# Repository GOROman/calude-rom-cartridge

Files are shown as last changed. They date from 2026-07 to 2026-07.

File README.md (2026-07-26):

# Famicom ROM Cartridge (M5Stamp S3 + NROM/CNROM)

ファミコン実機で動作するカートリッジ基板。物理ROMの代わりに
**M5Stamp S3 (ESP32-S3)** を搭載し、電源投入時にROMイメージをSRAMへ
転送してファミコンにバスを明け渡す「SRAMロード&ハンドオーバー方式」を
採用しています。NROM/CNROMに対応し、ES8388によるI2S音声ミックスと
SLG46826G GreenPAKによるOPMレジスタ捕捉回路をオプション搭載できます。

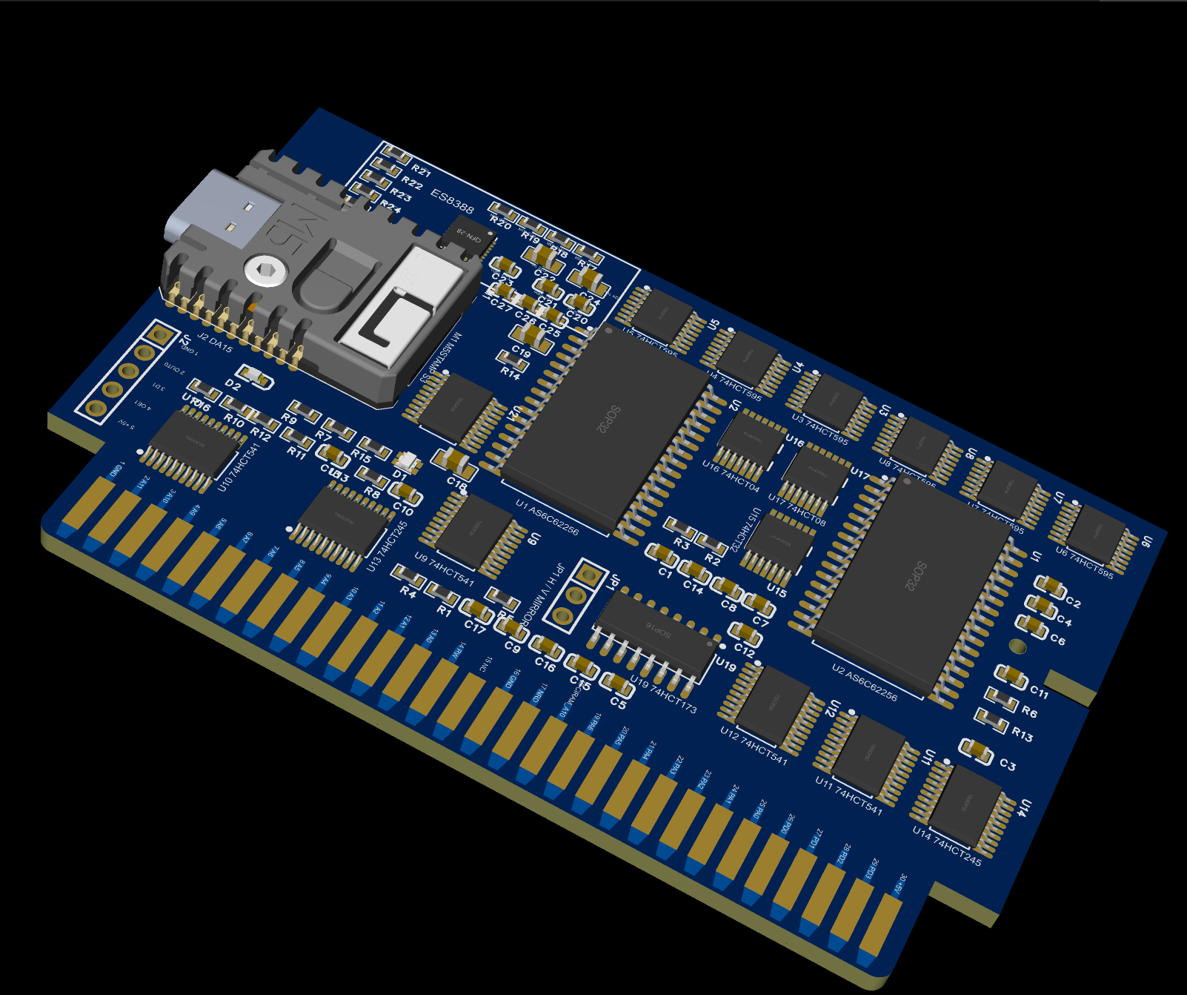
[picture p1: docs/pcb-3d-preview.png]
M5Stamp S3搭載ファミコンカートリッジ基板の3Dプレビュー


## 使い方 (UX)

1. カートリッジを挿してファミコンの電源を入れる
2. ESP32がSRAMへROMをロード(約1秒、完了をステータスLEDで通知)
3. 本体の **RESETボタンを押す** → ゲーム起動

※カートリッジ端子にはカート側から操作できるリセット線が無いため、この手順が必要。

## 構成

- マッパー: **NROM / CNROM** (PRG 32KB、CHRは最大4バンク)
- ROM相当: M68AF127B SRAM ×2 (PRG/CHR)
- ロード経路: 74HCT595 シフトレジスタチェーン ×2
- バス分離: 74HCT541/245 バッファ、74HCT32 ゲーティング
- 音声: M5Stamp S3のI2S → ES8388 → カートリッジ音声端子45/46へミックス（オプション、未実装でも動作）
- 拡張ロジック: SLG46826G GreenPAKをM5Stamp S3からI2Cで書き換え、OPMレジスタ書込みを捕捉
- 外形: 純正シェル互換の段付き外形（最大90×56.8mm、主要部90×46.1mm）、板厚1.2mm
- 60ピンエッジ: 全端子幅1.60mm、先端テーパー、垂直引き込み、挿入側左右角R1.524mm
- ケース: M5Stamp S3のUSB-C位置に合わせた開口付きSTLを収録

## 使用部品と役割

| Ref | 部品 | 数 | 役割 |
|---|---|---:|---|
| M1 | M5Stamp S3 (ESP32-S3) | 1 | `.nes`ファイルの保存・展開、SRAMへのROM転送、WiFi UI、BLEコントローラ処理を担当 |
| U1 | M68AF127B SRAM (128K×8) | 1 | CPUから読み出されるPRG-ROMデータを保持。A15/A16はLow固定で32KBを使用 |
| U2 | M68AF127B SRAM (128K×8) | 1 | PPUから読み出されるCHR-ROMデータを保持。A15/A16はLow固定、CNROM時は最大4バンクを使用 |
| U3–U8 | 74HCT595 | 6 | M5Stamp S3の少数GPIOを24bitのアドレス・データ信号へ展開し、LOAD時にPRG/CHR SRAMへ書き込む |
| U9–U12 | 74HCT541 | 4 | ファミコン側のCPU/PPUアドレス・制御バスをバッファし、LOAD時は本体とSRAMを切り離す |
| U13, U14 | 74HCT245 | 2 | PRG/CHRデータバスをバッファし、RUN時のみSRAMからファミコン本体へデータを出力 |
| U15 | 74HCT32 | 1 | `/ROMSEL`、`R/W`、PPU制御信号を組み合わせ、SRAMとデータバッファの出力許可信号を生成 |
| U16 | 74HCT04 | 1 | `MODE`や`R/W`などの制御信号を反転 |
| U19 | 74HCT173 | 1 | CNROMのCHRバンク番号を保持し、CHR SRAMのA13/A14を切り替える |
| U20 | ES8388 | 1 | M5Stamp S3のI2Sをアナログ音声へ変換。45/46番端子へのミックス回路を含むオプション実装 |
| U21 | SLG46826G GreenPAK | 1 | OPM用メモリマップドI/Oの書込み捕捉。M5Stamp S3からI2Cでインシステム設定 |
| Q1, Q2 | BSS138 | 2 | GreenPAKの5V I2CとM5Stamp S3の3.3V I2Cを双方向レベル変換 |
| J2 | 5ピンコネクタ | 1 | ファミコン前面DA15拡張ポートとの接続用。OUT0、`/OE joy1`、Joypad D1を扱う |
| JP1 | 3パッド半田ジャンパ | 1 | CIRAM A10の接続先をPA10/PA11から選び、縦・横ミラーリングを設定 |
| D1, D2 | 0603 LED | 2 | 電源表示と、ROMロード完了・RESET操作のステータス表示 |
| R15, R16 | 330Ω | 2 | LEDの電流制限 |
| R1–R4 | 10kΩ/20kΩ | 4 | DA15からの5V入力信号をM5Stamp S3用の3.3Vへ分圧 |
| R（プルアップ/ダウン） | 10kΩ | 8 | 起動時やLOAD時のMODE、SRAM、バッファ制御信号を安全な状態に固定 |
| R（直列） | 33Ω | 4 | 74HCT595の高速シフト信号のリンギングとノイズを抑制 |
| C（パスコン） | 100nF | 17 | 各ICの電源ノイズを除去 |
| C（バルク） | 22µF + 10µF | 各1 | 5V入力とM5Stamp S3近傍の電源変動を吸収 |
| R26–R29 | 4.7kΩ | 4 | GreenPAK I2Cレベル変換回路の3.3V側・5V側プルアップ |
| C28 | 100nF | 1 | GreenPAKのVDD/VDD2デカップリング |
| 0Ω抵抗 | 0Ω | 2 | カートリッジ音声端子45–46とピン31電源接続のオプション設定 |
| 60ピン・エッジコネクタ | 硬質金推奨の基板端子 | 1 | 全端子同一幅、先端テーパー。CPU/PPUバス、電源、音声、CIRAM信号へ接続 |

ロジックICには、M5Stamp S3の3.3V出力を5V系で確実にHigh判定できる **74HCTシリーズ**を使用します（74HCシリーズへの置き換えは不可）。

### 秋月電子で購入できる部品

| 対象 | 秋月電子の商品 | 適合・注意事項 |
|---|---|---|
| U1, U2 | [M68AF127B SRAM 1Mbit（5個入）](https://akizukidenshi.com/catalog/g/g101634/) | SOP32、1.27mmピッチ、5V、55ns。本基板の採用品。在庫限り |
| M1 | [M5Stamp S3](https://akizukidenshi.com/catalog/g/g118194/) | 基板実装にはピンヘッダーまたはキャステレーション接続を使用 |
| J2 基板側 | [JST XH 5Pベース付ポスト B5B-XH-A](https://akizukidenshi.com/catalog/g/g112250/) | 2.5mmピッチ、スルーホール。現在のJ2フットプリントをこの寸法に合わせる |
| J2 ケーブル側 | [JST XH 5Pハウジング XHP-5](https://akizukidenshi.com/catalog/g/g112258/) | コンタクトまたはコンタクト付きコードが別途必要 |
| C（100nF） | [0.1µF 50V X8L 1608](https://akizukidenshi.com/catalog/g/g116143/) | 各ICのパスコンとして使用可能 |
| C（10µF） | [10µF 16V X5R 2012](https://akizukidenshi.com/catalog/g/g107542/) | M5Stamp S3近傍のバルクコンデンサとして使用可能 |
| C（22µF） | [22µF 25V X5R 2012](https://akizukidenshi.com/catalog/g/g108240/) | 5V入力のバルクコンデンサとして使用可能 |
| D1 | [緑色チップLED 1608 OSTG1608C1A](https://akizukidenshi.com/catalog/g/g106417/) | 極性とフットプリントのピン1方向を実装前に確認 |
| D2 | [赤色チップLED 1608 SML-E12V8WT86](https://akizukidenshi.com/catalog/g/g111879/) | 極性とフットプリントのピン1方向を実装前に確認 |
| R（10kΩ） | [チップ抵抗 1/10W 10kΩ 1608](https://akizukidenshi.com/catalog/g/g115029/) | プルアップ、プルダウン、分圧に使用可能。販売単位に注意 |
| R（20kΩ） | [チップ抵抗 1/10W 20kΩ 1608](https://akizukidenshi.com/catalog/g/g106203/) | DA15入力の分圧に使用可能。販売単位に注意 |
| R（330Ω） | [チップ抵抗 1/10W 330Ω 1608](https://akizukidenshi.com/catalog/g/g116125/) | LED電流制限に使用可能 |
| U21 | [SLG46826G GreenPAK](https://akizukidenshi.com/catalog/g/g118384/) | TSSOP-20。I2Cでインシステム設定可能 |

74HCT595、74HCT541、74HCT245、74HCT32、74HCT04、74HCT173については、基板の表面実装フットプリントに適合する秋月電子の商品を確認できていません。74HC/LV/VHC品は入力しきい値や動作条件が異なるため代用せず、HCT品をLCSCなどから調達します。

## 機能

- **WiFi転送**: softAP (`FC-CART`) + Web UI (`http://192.168.4.1/`) で .nes アップロード/ゲーム切替
- **Bluetoothコントローラ**: 拡張ポート(DA15)経由でパッド入力を注入(BLEパッド → Bluepad32 統合予定)。カートリッジ端子にはコントローラ信号が無いため J2→DA15 ケーブルを使用
- **I2S音声**: ES8388を使用する構成では、M5Stamp S3のI2S音声を端子45/46へミックス
- **GreenPAK設定**: SLG46826GをI2C経由で更新し、OPMエミュレーション用レジスタ書込みを捕捉

## 現在の設計状態

EasyEDA Proの現行基板は `PCB2` です。部品配置、ケース用穴、USB-C開口、
60ピン端子のテーパーと左右下角Rを反映済みです。配線とDRCは作業中で、
現在のGerberは発注用の最終版ではありません。

## ファームウェア開発 (ESP-IDF)

```sh
cd firmware
idf.py set-target esp32s3
idf.py build flash monitor
```

## ディレクトリ

- `docs/` — アーキテクチャ設計、寸法、発注仕様
- `pcb/` — EasyEDA設計、基板資料、フットプリント、Gerber/BOM/座標データ、ケースSTL
- `firmware/` — ESP32-S3 ファームウェア (PlatformIO)

基板ファイルの構成は [pcb/README.md](pcb/README.md)、設計詳細は
[docs/architecture.md](docs/architecture.md) を参照。

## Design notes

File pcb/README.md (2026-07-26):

# PCB

基板設計・製造・ケース関連のファイルは、このディレクトリに集約しています。

## 構成

| ディレクトリ | 内容 |
|---|---|
| `easyeda/` | 現行EasyEDAプロジェクトの書き出し |
| `easyeda/archive/` | 旧EasyEDAプロジェクト |
| `design-docs/` | BOM設計表、ネットリスト仕様、PCB作業状況 |
| `footprints/` | カスタムフットプリント資料 |
| `fabrication/` | Gerber、実装BOM、Pick & Place |
| `case/` | ケースSTL、USB開口生成スクリプト |

## 現行ファイル

- EasyEDAプロジェクト: `easyeda/calude-rom-cartridge.epro2`
- Gerber: `fabrication/calude-rom-cartridge-PCB2-gerber.zip`
- 実装BOM: `fabrication/calude-rom-cartridge-PCB2-bom.csv`
- Pick & Place: `fabrication/calude-rom-cartridge-PCB2-pick-and-place.csv`

製造データはEasyEDAのPCB2から直接生成しています。BOMとPick & Placeは
EasyEDA標準のUTF-16LE形式です。

## 注意

現在のGerberは設計スナップショットです。発注前にDRC、未配線、部品重なり、
エッジフィンガーの向き、板厚1.2mm、金端子処理を再確認してください。

PCB2の60ピン端子は全端子を同じ幅（63 mil）に統一し、先端を左右対称の
テーパー形状にしています。端子への引き込みは垂直・24 milで、挿入側の
左右基板角はR60 milです。端子15・47はNCのため引き込み配線はありません。

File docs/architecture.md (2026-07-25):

# アーキテクチャ設計

## マッパー対応: NROM + CNROM (Mapper 0/3)

CHRバンクセレクトラッチ(74HCT173, U19)を搭載し、**NROM(Mapper0)とCNROM(Mapper3)の両対応**。

- CNROMはCPUの$8000-$FFFF書き込みでD0-D1をラッチしCHRバンク(8KB単位)を切替える
- 実装: U19=74HCT173。CP=M2、#E1/#E2=WR_STROBE(=NROMSEL OR RW、74HCT32の空きゲート)、#OE=MODE_N(RUN時のみ駆動)、Q0/Q1→CHR SRAM A13/A14
- ロード中はESP32(595 U8のA13/A14出力)がCHRアドレス上位を駆動、実行中は173が駆動(MODEで排他)
- CHR SRAM(M68AF127B, 128KB)はA15/A16をLow固定し、現設計では最大4バンク(32KB CHR)まで使用。対象ゲーム `calude-famicom-game` はCNROM/PRG32KB/CHR16KB(2バンク)/垂直ミラー
- PRG書込は/WEをESP32が常時Highに保持するためバンク切替書き込みでSRAMは破壊されない

## 方式判断

ESP32-S3によるカートリッジバスの直接エミュレーションは不成立:

- NROMは CPU側 (A0-A14, D0-D7, R/W, /ROMSEL, M2 ≈26本) + PPU側 (PA0-PA13, PD0-PD7, /RD ≈23本) の**約49信号が同時に必要**。M5Stamp S3の使用可能GPIOは約23本。
- バス応答は /ROMSEL 立下りから ~300-400ns 以内。PPU側は独立した並行フェッチ。RP2040系 (PicoROM等) はPIO+オーバークロック+30GPIOで成立しているが、ESP32-S3にPIO相当はなく、WiFi/RTOS併走で2系統の決定的応答は不可能。

→ **SRAMロード&ハンドオーバー方式**を採用。

## ブロック図

```
             ファミコン 60ピンエッジ (2×30, 2.54mm)
   CPU側                                    PPU側
    A0-A14,/ROMSEL,R/W →[74HCT541×2]→+       PA0-PA12 →[74HCT541×2]→+
    D0-D7 ←[74HCT245]←+              |       PD0-PD7 ←[74HCT245]←+  |
                      |              |                           |  |
               +------+--------------+--+              +---------+--+----+
               | U1 PRG SRAM M68AF127B   |              | U2 CHR SRAM     |
               +-----------+------------+              +--------+--------+
                           |                                    |
              [74HCT595×3 チェーンA]                [74HCT595×3 チェーンB]
                           \____________    ____________________/
                                        \  /
                          M5Stamp S3 (3.3V, 使用GPIO ~10本)
                          SER_A/SER_B, SRCLK, RCLK, /OE_595,
                          /WE_PRG, /WE_CHR, MODE, LED, BTN
```

- ミラーリング: CIRAM A10 (pin18) ← 半田ジャンパ → PA10 (V) / PA11 (H)
- CIRAM /CE (pin48) ← 直結 → PPU /A13 (pin49) ※NROM慣例
- 音声: pin45 — 0Ωブリッジ — pin46
- 電源: 本体+5V → SRAM/74HCTレール + M5Stamp 5V入力(内蔵3.3Vレギュレータ)

## 動作モード

`MODE` 線1本で切替(抵抗でLOAD側にプル → ESP32起動前は必ず不活性):

- **LOAD**: コンソール側541/245無効(本体から見てhi-Z=オープンバス、衝突なし)。595チェーンがSRAMのアドレス+データを駆動、ESP32が/WEをパルス。
- **RUN**: 595 /OE=H (hi-Z)。コンソール側バッファ有効。SRAMの/CE//OEは 74HCT32 で /ROMSEL+R/W (PRG) / PPU A13+/RD (CHR) からゲート。

## 起動シーケンス

1. 電源ON。MODE=LOAD(プルダウン)。本体CPUはオープンバスのゴミを実行するが電気的衝突なし。
2. ESP32起動(~300ms)→ LittleFSマウント → .nesのiNESヘッダ解析。
3. PRG 32,768バイト(16KBイメージは2回ミラー書込)をチェーンAへ: 15bitアドレス+8bitデータをシフト→ラッチ→/WE_PRGパルス。CHR 8,192バイトをチェーンBへ。シフトクロック≤10MHzで計~100-200ms。
4. MODE=RUN → LED緑。
5. **ユーザーが本体RESETを押す** → CPUが$FFFCをSRAMから読みゲーム起動。
6. RUN中もESP32は生存(将来: WiFi UI)。別ゲーム選択時は MODE=LOAD→再ロード→RESET再押下。

## 信号設計

ピンマッピング (NESdev Cartridge connector 準拠):

- CPU: GND=1/16, A11-A0=2-13, R/W=14, /IRQ=15(未使用), /RD(PPU)=17, M2=32, A12-A14=33-35, D7-D0=36-43, /ROMSEL=44, +5V=30
- PPU: CIRAM A10=18, PA6-PA0=19-25, PD0-PD3=26-29, /WR=47, CIRAM /CE=48, PPU /A13=49, PA7-PA12=50-55, PA13=56, PD7-PD4=57-60
- 音声: 45→46 0Ωブリッジ。pin31: 5Vプレーンへ0Ωオプション。

ゲーティング (74HCT32):

- PRG SRAM: /CE = /ROMSEL(バッファ後)、/OE = /ROMSEL OR R/W反転考慮 OR (NOT MODE) — $8000+への書込衝突防止のためR/Wを含める。/WE = ESP32 (プルアップ)。
- CHR SRAM: /CE = PPU A13 OR (NOT MODE)、/OE = PPU /RD、/WE = ESP32。PPU /WR はSRAMに非接続(CHR-ROM相当)。
- 全体5Vロジック。ESP32(3.3V)→HCT入力は VIH=2.0V なので直結可。シフト線は短く+直列33Ω。
- パスコン: 各IC 100nF、エッジ付近にバルク22µF。

## ESP32 ピンバジェット

| 信号 | 本数 |
|---|---|
| SER_A, SER_B | 2 |
| SRCLK, RCLK (チェーン共有) | 2 |
| /OE_595 (共有) | 1 |
| /WE_PRG, /WE_CHR | 2 |
| MODE | 1 |
| LED (内蔵SK6812=G21), BTN | 1 |
| 予備 | ~11 |

## 部品表(主要)

| Ref | 部品 | LCSC候補 |
|---|---|---|
| U1,U2 | M68AF127B (128K×8 SRAM, 4.5-5.5V, 55ns, SOP32) | 秋月電子 101634（5個入）/ 101083（1個） |
| U3-U8 | 74HCT595 ×6 | 74HCT595D系 |
| U9-U12 | 74HCT541 ×4 | |
| U13,U14 | 74HCT245 ×2 | |
| U15 | 74HCT32 | |
| M1 | M5Stamp S3 | ユーザー支給 |

**HCT必須**(HC不可): 3.3V駆動のVIH互換のため。

## 基板外形 (NESdev実測)

- 段付き外形の最大寸法 **90 × 56.8 mm**、主要部 **90 × 46.1 mm**、板厚 **1.2mm** (1.6mmはコネクタを痛めるため不可)
- J3の60ピン・デバッグ用メスコネクタはバスを1:1でパススルーする。基板外形はケース互換のままだが、実装高さがあるためケース組み込み時はDNP
- エッジフィンガー: 2×30、2.54mmピッチ、信号パッド幅1.6mm/電源2.6mm、挿入深さ10.7mm、パッド上端〜基板端3mm、レジスト開口4mm
- JLCPCB: ENIG以上(理想: 金フラッシュ+30°ベベル)。フィンガー1mm以内に部品/ビア禁止、フィンガーは一辺のみ。
- 参照: DameNoSupaplex/famicom-cartridge-nrom (KiCad)、EasyEDAコミュニティ FAMICOM CARTRIDGE PCB フットプリント
- M5Stamp S3 (~24×20×4.5mm) はシェルの厚い側キャビティに配置。樹脂シェルなのでWiFi透過OK。

## WiFi 転送 (実装済み)

ESP32-S3 が softAP (SSID: `FC-CART`) + HTTPサーバを起動。`http://192.168.4.1/` で:

- `.nes` ファイルのアップロード (LittleFS 4MBパーティションに保存、NROM数十本分)
- ゲーム一覧から選択 → その場でSRAM再ロード → 本体RESET押下で切替
- 選択したゲームは `autoload.txt` に記憶し次回電源ONで自動ロード

## Bluetooth コントローラ対応 (拡張ポート経由)

**カートリッジ端子にはコントローラ信号が存在しない**($4016/$4017は本体内部でデコードされ、シリアルデータは本体内蔵ラッチ/拡張ポートから供給される)。よってコントローラ入力の注入は **DA15拡張ポート** 経由で行う(8BitDoレシーバと同方式)。

構成: カートリッジ基板上に J2 コネクタ(5線)を設け、DA15プラグへのケーブルで接続。

| J2信号 | DA15ピン | 方向 | レベル対策 |
|---|---|---|---|
| GND | 1 | — | — |
| OUT0 (ストローブ) | 12 | 本体→ESP32 | 抵抗分圧 5V→3.3V |
| /OE joy1 ($4016リード) | 14 | 本体→ESP32 | 抵抗分圧 5V→3.3V |
| Joypad1 /D1 (データ) | 13 | ESP32→本体 | 3.3V直結 (TTL VIH=2.0Vで成立) |
| +5V | 15 | — | (給電はカートエッジ側を使用、未接続可) |

動作: 4021シフトレジスタ相当をGPIO割り込みでエミュレート(`joypad_out.c` 実装済み)。OUT0でボタン状態をラッチ、$4016リードの立上りエッジで次ビットへシフト。データは拡張コントローラ扱い($4016 D1)なので物理コントローラ(D0)と衝突しない。ゲーム側は標準+拡張の両対応読取りが一般的。

- リスク: ISR応答遅延(~1-2µs)による取りこぼし。問題があれば74HC165(物理シフトレジスタ)+パラレル駆動に切替(フォールバック設計)。
- BLE入力元: **Bluepad32** (ESP-IDFコンポーネント統合、BLEゲームパッド: Xbox Series等) を `joypad_out_set_buttons()` に接続する。ESP32-S3はBLEのみ(BT Classic非対応)のため、Classic専用パッド(Switch Pro等)は不可。統合はv1.2マイルストーン。

## タイミングマージン

RUN経路: 541 (~9ns) + SRAM (55ns) + 245 (~9ns) ≈ **75ns** ≪ バジェット ~350ns。十分。

## リスクと対策

| リスク | 対策 |
|---|---|
| ロード中の本体ゴミ実行 | 全バッファhi-Z(衝突なし)+「LED緑でRESET」フロー |
| $8000+書込衝突 | PRG /OE に R/W をゲート |
| PPU /WR によるCHR破壊 | CHR /WE をESP32+プルアップで常時H |
| シェル個体差 | 発注前に実物シェルで実測確認 |
| SRAM読み戻し検証不可 | アップロード時CRC+控えめなシフトクロック |

## 参考資料

- https://www.nesdev.org/wiki/Cartridge_connector
- https://www.nesdev.org/wiki/Famicom_cartridge_dimensions
- https://github.com/DameNoSupaplex/famicom-cartridge-nrom
- https://github.com/wickerwaka/PicoROM (RP2040 ROMエミュレータ先行事例)
- https://jlcpcb.com/help/article/jlcpcb-gold-fingers

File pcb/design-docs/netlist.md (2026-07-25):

# ネットリスト設計 (回路図作成の元データ)

全体は5Vロジックドメイン。ESP32(3.3V)出力はHCT入力(VIH=2.0V)に直結。

## 制御ネット

| ネット | 生成元 | プル | 意味 |
|---|---|---|---|
| MODE | ESP32 GPIO8 | 10k PD | H=RUN / L=LOAD (電源投入直後は必ずLOAD) |
| MODE_N | U16 74HCT04 (MODEを反転) | — | 全541/245の/OE系イネーブル (L=RUN有効) |
| /OE_595 | ESP32 GPIO5 | 10k PU | 595出力イネーブル (起動前は必ず無効) |
| /WE_PRG | ESP32 GPIO6 | 10k PU | PRG SRAM書込パルス |
| /WE_CHR | ESP32 GPIO7 | 10k PU | CHR SRAM書込パルス |

## ゲーティング (U15 74HCT32 + U16 74HCT04)

| ネット | 論理 | 用途 |
|---|---|---|
| nRW | NOT R/W_BUF (U16) | リード判定 |
| /OE_PRG | /ROMSEL_BUF OR nRW | PRG SRAM /OE と U13(245) /OE |
| /OE_C245 | PA13_BUF OR /RD_BUF | CHR側 U14(245) /OE |
| /CE_PRG | = /ROMSEL_BUF | PRG SRAM /CE |
| /CE_CHR | = PA13_BUF | CHR SRAM /CE (パターンテーブルはA13=0) |
| /OE_CHRSRAM | = /RD_BUF | CHR SRAM /OE |

LOAD中(バッファhi-Z)のバッファ出力ネットのプル設定:

- /ROMSEL_BUF: 10k PD → LOAD中 /CE_PRG=L(書込可能) ✔
- R/W_BUF: 10k PD → nRW=H → /OE_PRG=H(SRAM出力オフ) ✔
- PA13_BUF: 10k PD → /CE_CHR=L(書込可能) ✔
- /RD_BUF: 10k PU → CHR出力オフ ✔

## PRG側 (CPUバス)

- U9 74HCT541: エッジ A0-A7 → PRG_A0-A7。/OE1=/OE2=MODE_N
- U10 74HCT541: エッジ A8-A14, R/W, /ROMSEL → PRG_A8-A14, R/W_BUF, /ROMSEL_BUF。/OE=MODE_N
- U13 74HCT245: B側=PRG_D0-D7、A側=エッジ D0-D7。DIR=B→A固定、/OE=/OE_PRG
- U1 M68AF127B: A0-A14=PRG_A*、A15/A16=GND、DQ0-DQ7=PRG_D*、E1=/CE_PRG、E2=+5V、G=/OE_PRG、W=/WE_PRG

## CHR側 (PPUバス)

- U11 74HCT541: エッジ PA0-PA7 → CHR_A0-A7。/OE=MODE_N
- U12 74HCT541: エッジ PA8-PA12, PA13, /RD → CHR_A8-A12, PA13_BUF, /RD_BUF。/OE=MODE_N
- U14 74HCT245: B側=CHR_D0-D7、A側=エッジ PD0-PD7。DIR=B→A固定、/OE=/OE_C245
- U2 M68AF127B: A0-A14=CHR_A*、A15/A16=GND、DQ0-DQ7=CHR_D*、E1=/CE_CHR、E2=+5V、G=/OE_CHRSRAM、W=/WE_CHR
- J3 DEBUG 60PIN: J1の1〜60番ピンを同番号で1:1接続するデバッグ用メスコネクタ。ケース組み込み時DNP
- PPU /WR (47): SRAMに非接続 (CHR-ROM相当、書込不可)

## 595チェーン (LOAD時のアドレス/データ注入)

チェーン順 (ESP32 SER→): [DATA] → [ADDR下位] → [ADDR上位]。24bit送出(MSBファースト)後の配置:

- チェーンA (PRG): U3=DATA (QH=D7…QA=D0) → U4=ADDR下位 (QH=A7…QA=A0) → U5=ADDR上位 (QH=未使用, QG=A14…QA=A8)
- チェーンB (CHR): U6=DATA → U7=ADDR下位 → U8=ADDR上位 (同構成、A13/A14未使用)
- SRCLK(GPIO3)/RCLK(GPIO4)は両チェーン共有、SER_A=GPIO1、SER_B=GPIO2
- 全595 /OE=/OE_595、/SRCLR=+5V
- 595出力はSRAMのアドレス/データネットに直結 (541/245とはMODEで排他)

## エッジその他

- CIRAM /CE (48) — PPU /A13 (49) 直結
- CIRAM A10 (18) — 3パッド半田ジャンパ — PA10 (V) / PA11 (H)
- 音声: 45 — 0Ω — 46
- /IRQ (15), M2 (32): 未接続 (M2はテストパッドのみ推奨)
- +5V (30, 31要確認) → 5Vプレーン → M5Stamp S3 5V入力
- GND (1, 16)

## GreenPAK / OPMレジスタ捕捉

U21 (SLG46826G) はCPUのOPMレジスタ書込みを捕捉し、M5Stamp S3から
インシステム設定を書き換えられるようにする。

- U21 VDD/VDD2 = +5V、GND = GND、C28=100nF
- 入力: D0-D7、A0、R/W、M2、/RESET、/OPM_CS
- 出力予約: OPM_IRQ、OPM_WR_STB
- /OPM_CSは$5000-$5FFFを外部ロジックでデコードして生成する
- GreenPAK I2C側: GPAK_SDA_5V / GPAK_SCL_5V
- M5Stamp側: 既存ES8388と共用のGPIO40(SDA) / GPIO41(SCL)
- Q1/Q2=BSS138、R26-R29=4.7kΩで5V↔3.3V双方向レベル変換する
- GreenPAKのI2CアドレスはES8388 (0x10) と衝突しない値に設定する

## J2: 拡張ポート(DA15)ケーブル用コネクタ (BLEパッド注入)

| J2 | 信号 | DA15 | レベル |
|---|---|---|---|
| 1 | GND | 1 | — |
| 2 | OUT0 | 12 | 5V→分圧(10k/20k)→ESP32 GPIO9 |
| 3 | JOY1 /D1 | 13 | ESP32 GPIO11 → 直結(3.3V=TTL H) |
| 4 | /OE joy1 | 14 | 5V→分圧→ESP32 GPIO10 |
| 5 | +5V | 15 | 未接続可 |

## パスコン

各IC 100nF (17個)、5Vエントリに22µF、M5Stamp近傍に10µF。

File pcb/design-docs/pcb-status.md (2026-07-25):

# PCB 設計状況 (EasyEDA Pro プロジェクト: calude-rom-cartridge)

## 完了

- 回路図: 54部品・129ネット、ネット名スタブ方式で全結線。ERC エラー0/警告3
- PCB へネット取込済み(部品はパッドのネットで自動識別)
- 基板外形: 純正段付きプロファイル 90×56.8mm、板厚1.2mm。タン78.4mm/肩46.1mm/サイドノッチy20.9-22.9mm
- エッジフィンガー: フリーパッド60枚(1.8×7.62mm、ピン1のみ8.89mmロング、ネット割当済)
- LED追加: 電源LED(緑D1、+5V常時点灯)+ステータスLED(赤D2、GPIO14駆動)、R15/R16(330Ω)
- **配置最適化**: 接続クラスタ順(CHR系=左、PRG系=右、バッファをフィンガー寄り、シフトレジスタ上段、パスコンをIC隣接)でラッツネスト短縮
- **片面(TOP)実装**(リフロー前提): 全ICをTSSOP/TSOP化。M5Stamp右上(中心78.9178,20.32mm、USB右向きrot90)、パスコンを各ICに隣接配置。USB外形端をケース右内壁から0.66mm内側に合わせ、全銅箔端は基板内に保持。53部品を穴/ノッチ/境界/重なりゼロで機械検証済み
- GreenPAK U21 (SLG46826G/TSSOP-20) をPCB2のM5Stamp左側に追加。回路図にはCPUバス捕捉信号と5V側I2Cネットを追加済み
- ベタ: TOP=+5V、BOTTOM=GND (本体領域、ノッチ回避多角形、優先度1)
- 穴: ネジ穴φ3@(39.5,19.8mm)、中央φ5@(45,10.3mm) NPTH配置済み

## 残作業

1. **配線**: EasyEDA Pro GUI で 布線 → 自動布線(クラウド)を実行、または手動配線
   - 優先: バッファ↔SRAM↔フィンガーの RUN 経路を短く
2. **DRC**: 配線後に実行(金フラッシュ 1mm クリアランスルール含む)
3. ~~シェルねじボス穴~~ → NESdev準拠位置で配置済み(実物シェルで最終確認推奨)
4. **3D/シェル干渉確認**: M5Stamp S3 (高さ4.5mm) はシェル厚側キャビティに配置済み。USB-C開口付き上シェルは `Dendy_top_usb.stl`
5. **製造出力**: ガーバー生成 → JLCPCB (1.2mm厚 / ENIG or 金フラッシュ+ベベル指定)
6. **GreenPAK周辺**: BSS138×2、I2Cプルアップ4本、C28、/OPM_CSデコード回路を配置・配線してDRC

## PCB上のリファレンス対応

回路図とPCBのデザイナタは自動採番のため、論理名↔ネットで識別する:
U_PRG/U_CHR=SRAM、S_*=74HCT595、B_*541/B_*245=バッファ、G_OR=HCT32、
G_AND=HCT08、G_INV=HCT04、M1=M5Stamp S3、J2=DA15ケーブル、JP1=ミラーリング

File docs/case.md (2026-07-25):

# ケース適合 (Dendy/Famicom cartridge, Thingiverse thing:3357677)

STL: `pcb/case/thing-3357677/files/Dendy.stl`(下シェル)、`Dendy_top.stl`(上シェル)。画像・README・LICENSEも同梱。作者 5rw。

USB-C開口付き上シェル: `pcb/case/thing-3357677/files/Dendy_top_usb.stl`。
M5Stamp S3のUSB中心に合わせ、右側面へ **11.0mm幅 × 5.5mm高** の開口を追加している。
元STLは変更せず、`pcb/case/add_usb_opening.py` で再生成できる。

## STL解析による寸法(バイナリSTLをパースして実測)

| 項目 | 値 |
|---|---|
| ケース外寸(各シェル) | 107.8 (X) × 69.2 (Y) × 9.5 (Z) mm |
| 合計厚(2シェル) | 約19mm |
| 内部キャビティ(壁内側) | 約 96 (X, ±48) × 62 (Y, ±31) mm |
| コネクタスロット/底部開口 | X方向 約90mm (±45)、Y下端(-34.6側) |
| PCB受け面(ledge)Z | 約7mm |

座標は STL 原点(ケース中心)基準。

## 基板適合判定 ✓

現行基板(90mm幅 × 56.8mm高、タン78.4mm)は本ケースに収まる:

- 基板幅 **90mm** = ケース底部コネクタ領域 **90mm** に一致(±45)
- タン **78.4mm**(±39.2)はスロット開口(±45)内に収まり、コンソール接点が届く
- 基板高 **56.8mm** < 内部キャビティ **62mm**(ラベル部の余裕あり)
- 基板幅 90mm < 内部キャビティ幅 96mm

## M5Stamp S3 / USB-C位置

- M1中心: 基板座標 **(78.9178, 20.32)mm**、回転 **90°**（USB右向き）
- STL座標変換: `stl_x = pcb_x - 45`、`stl_y = 11.5 - pcb_y`
- USB-C開口中心Y: STL座標 **-8.82mm**
- M1のUSB側外形端: 基板座標 **X=92.342mm**。ケース内壁 **X=93mm相当** から内側へ約0.66mm
- キャステレーションとテストパッドの銅箔端は基板右端 **X=90mm** 内に収まる

## ネジ穴(STL検出・準拠済み)

STLの垂直円柱特徴を検出: **対称な2穴 (±2.6, -11.9)mm(ケース中心原点)、径2mm、高さ5mm**。
基板座標へ変換(board_x=STL_x+45、board_y=STL_y-11.5 ※タンのショルダー46.1mm↔スロット面):
- 基板穴: **(42.4, -23.4)mm と (47.6, -23.4)mm、径2.2mm** に配置済み
- X方向はケース中心対称で確実。Y方向はメッシュからの位置合わせのため±数mmの不確実性あり → 3D/現物で最終確認推奨

## 残確認(3Dで要検証)

- **ネジ柱/穴の位置合わせ**: STL内部の柱クラスタは (±48,20)/(0,-12)付近に検出。基板の穴(φ3@39.5/19.8mm, 中央φ5@45/10.3mm)と厳密一致するかは3Dビューで確認推奨
- EasyEDA Pro の3Dビューに本STLを取り込んで、基板と重ねてクリアランス/ネジ位置を目視確認するのが確実
- 3Dプリント品のため実測公差あり。発注前に現物合わせ推奨

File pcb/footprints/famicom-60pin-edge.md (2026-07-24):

# ファミコン 60ピン カードエッジ フットプリント仕様

出典: DameNoSupaplex/famicom-cartridge-nrom ガーバー実測(シェル実装確認済基板)。EasyEDA Proに反映済み。

## 基板外形 (段付き、ガーバー実測)

- 本体: **100.33 × 40.64 mm**、板厚 **1.2 mm** (1.6mm不可)
- エッジタン(舌部): 幅 **78.74 mm** (x 10.795〜89.535)、突出 **11.43 mm**、根元コーナー面取り
- サイドノッチ: 左右 y 17.78〜20.955 mm 位置に深さ2.54mmの切欠き(シェル爪逃げ)
- エッジ処理: 金フラッシュ(硬質金)+ 30°ベベル推奨、最低ENIG

## フィンガー (両面 2×30、ガーバー実測)

- ピッチ: **2.54 mm**、列位置 x = 13.335 + 2.54c (c=0..29)
- パッド: **1.8 × 7.62 mm**、パッド下端は基板端から **1.905 mm**
- ピン1 (GND) のみロングパッド **1.8 × 8.89 mm** (下端0.635mm、先行接触用)
- 表裏の対応: ピンn (1-30, ラベル面) の真裏がピン n+30
- **向き**: 部品面(TOP)から見てピン1が右端列 / ラベル面(BOTTOM)から見てピン1が左端
- フィンガー領域 1.0 mm 以内: 部品・ビア禁止 (JLCPCB金フラッシュルール)

## ピン割当 (NESdev Cartridge connector)

| ピン | 信号 | ピン | 信号 |
|---|---|---|---|
| 1 | GND | 60 | PD4 |
| 2-13 | CPU A11-A0 | 57-59 | PD7-PD5 |
| 14 | R/W | 56 | PA13 |
| 15 | /IRQ (未使用) | 50-55 | PA7-PA12 |
| 16 | GND | 49 | PPU /A13 |
| 17 | PPU /RD | 48 | CIRAM /CE |
| 18 | CIRAM A10 | 47 | PPU /WR |
| 19-25 | PA6-PA0 | 46 | 音声OUT(本体へ) |
| 26-29 | PD0-PD3 | 45 | 音声IN(カートへ) |
| 30 | +5V | 44 | /ROMSEL |
| 31 | +5V(要実測確認) | 36-43 | D7-D0 |
| 32 | M2 | 33-35 | A12-A14 |

※ 実フットプリント作成時は DameNoSupaplex/famicom-cartridge-nrom (KiCad) の座標と突合して穴位置(シェルのネジボス逃げ)を決定する。

## 穴位置 (NESdev HVC-N/Cx/Gx/UxROM 準拠)

- ネジ穴1: φ3.0mm、左端から39.5mm / 上端から19.8mm
- 中央穴: φ5.0mm、基板中央(左端から45mm) / 上端から10.3mm
- 純正シェルのボス位置に対応。摩擦保持ではなくネジ固定可

## 純正プロファイル採用 (2026-07-24更新)

- 外形を純正 **90 × 56.8mm** の段付きプロファイルに変更(タン幅78.4mm / 46.1mmで肩、上部56.8mmまで拡張)
- サイドノッチ: 左右 y20.9〜22.9mm、深さ **4.5mm**(NESdev正規。深すぎるとEDA領域認識が破綻)
- 板厚はファミコン仕様 **1.2mm**

## フィンガー縦位置 (NESdev正規、2026-07-24補正)

- パッド上端 = ショルダー(46.1mm)から **3.0mm** 下 = 49.1mm
- 信号1.6×5.7mm → 49.1〜54.8mm、電源/GND 2.6×6.7mm → 49.1〜55.8mm
- パッド下端は基板端(56.8mm)から約1〜2mm。挿入時に本体接点がパッド域に乗る

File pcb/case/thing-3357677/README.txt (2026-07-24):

Dendy (Famicom) cartridge by 5rw on Thingiverse: https://www.thingiverse.com/thing:3357677

Summary:
This is a pirated cartridge Dendy (Famicom), made in China. Produced in the 1990s. Made to restore broken cartridges from the collection.Это пиратский картридж Dendy (Famicom), производство китай. Произведен в 1990 годах. Сделан для восстановления сломанных картриджей из коллекции.

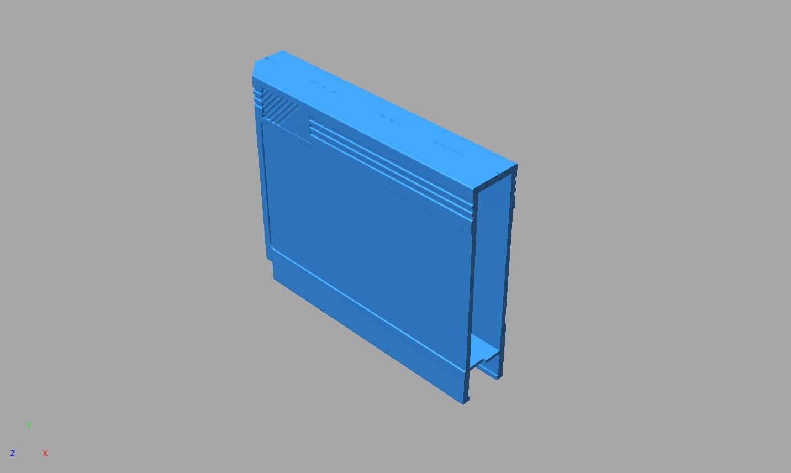
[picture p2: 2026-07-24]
pcb/case/thing-3357677/images/Dendy_all_r.jpg

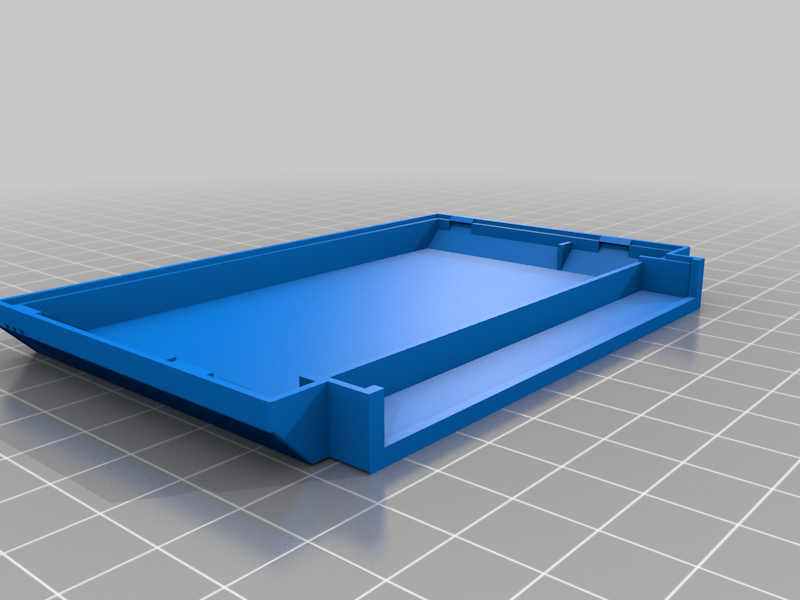
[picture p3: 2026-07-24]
pcb/case/thing-3357677/images/c267d29079fa6c6696ff125648821e60.png

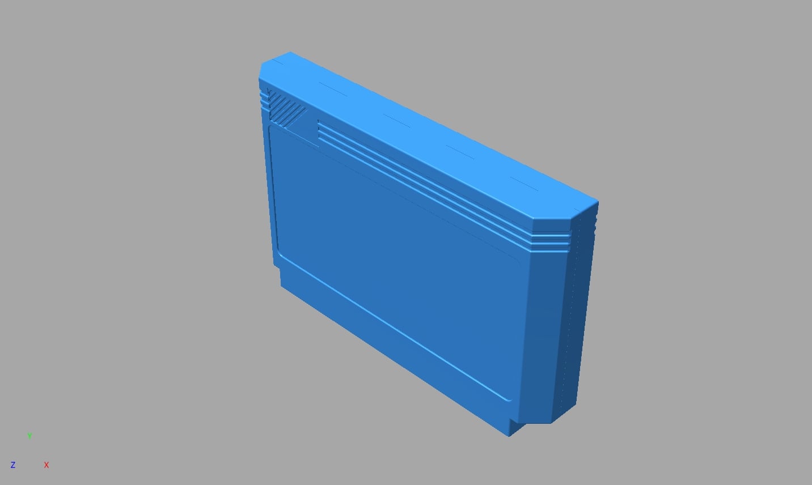
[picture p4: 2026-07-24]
pcb/case/thing-3357677/images/Dendy_all.jpg

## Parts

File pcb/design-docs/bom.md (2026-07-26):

# BOM (部品表)

全ICはTSSOP/TSOPパッケージ、片面(TOP)リフロー実装前提。

| Ref | 部品 | パッケージ | 数 | LCSC候補 | 備考 |
|---|---|---|---|---|---|
| U1, U2 | M68AF127B (128K×8 SRAM) | SOP-32 (450mil、1.27mmピッチ) | 2 | 秋月電子 101634 | 5V動作、55ns、A15/A16=GND、E2=+5V |
| J3 | 2×30ピン メスコネクタ | 2.54mmピッチ、60極 | 1 | 任意 | デバッグ用バスパススルー。ケース組み込み時DNP |
| U3-U8 | 74HCT595 | TSSOP-16 | 6 | 74HCT595D | HC不可(HCT必須) |
| U9-U12 | 74HCT541 | TSSOP-20 | 4 | 74HCT541D | |
| U13, U14 | 74HCT245 | TSSOP-20 | 2 | 74HCT245D | DIR固定 B→A |
| U15 | 74HCT32 | TSSOP-14 | 1 | 74HCT32D | ORゲート |
| U16 | 74HCT04 | TSSOP-14 | 1 | 74HCT04D | インバータ |
| U19 | 74HCT173 (4bit Dラッチ, 3ステート) | TSSOP-16 | 1 | 74HCT173D | CNROMバンクセレクト |
| U21 | SLG46826G GreenPAK | TSSOP-20 (0.65mmピッチ) | 1 | LCSC C3281959 / 秋月 118384 | OPMレジスタ書込み捕捉、M5StampからI2Cインシステム書換え |
| Q1,Q2 | BSS138 | SOT-23 | 2 | | GreenPAK 5V側－M5Stamp 3.3V側 I2C双方向レベル変換 |
| M1 | M5Stamp S3 | 2.54mmヘッダ/キャステレーション | 1 | ユーザー支給 | |
| J2 | 5ピン JST-XH or 2.54ヘッダ | — | 1 | | DA15ケーブル用 |
| JP1 | 3パッド半田ジャンパ | — | 1 | | ミラーリング H/V |
| R1-R2 | 10k+20k 分圧 ×2組 | 0603 | 4 | | OUT0, /OE入力 5V→3.3V |
| R* | 10k プル (MODE PD, /OE_595 PU, /WE×2 PU, バッファ出力プル×4) | 0603 | 8 | | |
| R* | 33Ω 直列 (SER/SRCLK/RCLK) | 0603 | 4 | | 信号品質 |
| C* | 100nF | 0603 | 17 | | 各IC |
| C* | 22µF | 0805 | 1 | | 5Vエントリ |
| D1 | LED 緑 (電源) | 0603/1608・2端子 | 1 | KT-0603G (LCSC C12624) | +5V直結で常時点灯。D2と同一ランド形状 |
| D2 | LED 赤 (ステータス) | 0603 | 1 | KT-0603R | ESP32 GPIO14駆動、ロード完了/RESET合図 |
| R15,R16 | 330Ω (LED電流制限) | 0603 | 2 | 0603WAF3300T5E | D1/D2用 |
| R26-R29 | 4.7kΩ | 0603 | 4 | 0603WAF4701T5E | I2C SDA/SCLの3.3V側・5V側プルアップ |
| C* | 10µF | 0805 | 1 | | M5Stamp近傍 |
| C28 | 100nF | 0603 | 1 | CC0603KRX7R9BB104 | U21 VDD/VDD2デカップリング |
| — | 0Ω (音声45-46、pin31オプション) | 0603 | 2 | | |

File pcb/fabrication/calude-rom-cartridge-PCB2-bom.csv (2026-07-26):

Supplier | Supplier Part | Manufacturer | Manufacturer Part | Value | Footprint | Designator | Comment | Quantity | No.
LCSC | C1591 | SAMSUNG(三星) | CL10B104KB8NNNC | 100nF | C0603 | C1,C2,C3,C4,C5,C6,C7,C8,C9,C10,C11,C12,C13,C14,C15,C16,C17 | 100nF | 17 | 1
LCSC | C45783 | SAMSUNG(三星) | CL21A226MAQNNNE | 22uF | C0805 | C18 | 22uF | 1 | 2
LCSC | C2980800 |  | CL21A106KAYNNNE |  | C0805 | C19 | CL21A106KAYNNNE | 1 | 3
LCSC | CL10A105KB8NNNC.1 | SAMSUNG(三星) | CL10A105KB8NNNC |  | C0603 | C20 | CL10A105KB8NNNC | 1 | 4
LCSC | CL10B104KB8NNNC.1 | SAMSUNG(三星) | CL10B104KB8NNNC |  | C0603 | C21,C23 | CL10B104KB8NNNC | 2 | 5
LCSC | CL21A106KAYNNNE_C2980800.1 |  | CL21A106KAYNNNE |  | C0805 | C22,C24 | CL21A106KAYNNNE | 2 | 6
LCSC | CL10A225KO8NNNC.1 | SAMSUNG(三星) | CL10A225KO8NNNC |  | C0603 | C25,C26,C27 | CL10A225KO8NNNC | 3 | 7
LCSC | C9900206921 |  | KT-0603RG |  | LED-SMD_4P-L1.6-W1.5_KT-0603RG | D1 | KT-0603RG | 1 | 8
LCSC | C2286 | KENTO | KT-0603R |  | LED-SMD_L1.6-W0.8-R-RD | D2 | KT-0603R | 1 | 9
 |  |  |  |  | HDR-TH_5P-P2.54-V-M | J2 | HDR-M_2.54_1x5P | 1 | 10
 |  |  |  |  | HDR-TH_3P-P2.54-V-M | JP1 | HDR-M_2.54_1x3P | 1 | 11
LCSC | C9900194829 |  | M5_STAMP-S3_SMD |  | COMM-SMD_M5_STAMP-S3_SMD | M1 | M5_STAMP-S3_SMD | 1 | 12
LCSC | C23140 | UNI-ROYAL(厚声) | 0603WAF330JT5E | 33Ω | R0603 | R1,R2,R3,R4 | 33Ω | 4 | 13
LCSC | C25804 | UNI-ROYAL(厚声) | 0603WAF1002T5E | 10kΩ | R0603 | R5,R6,R7,R8,R9,R10 | 10kΩ | 6 | 14
LCSC | C4184 | UNI-ROYAL(厚声) | 0603WAF2002T5E | 20kΩ | R0603 | R11,R12 | 20kΩ | 2 | 15
LCSC | 0603WAF1002T5E.1 | UNI-ROYAL(厚声) | 0603WAF1002T5E |  | R0603 | R13,R25 | 0603WAF1002T5E | 2 | 16
LCSC | C21189 | UNI-ROYAL(厚声) | 0603WAF0000T5E | 0Ω | R0603 | R14 | 0Ω | 1 | 17
LCSC | C23138 | UNI-ROYAL(厚声) | 0603WAF3300T5E | 330Ω | R0603 | R15,R16 | 330Ω | 2 | 18
LCSC | 0603WAF330JT5E.1 | UNI-ROYAL(厚声) | 0603WAF330JT5E |  | R0603 | R17,R18,R19,R20 | 0603WAF330JT5E | 4 | 19
LCSC | 0603WAF1001T5E.1 | UNI-ROYAL(厚声) | 0603WAF1001T5E |  | R0603 | R21,R22 | 0603WAF1001T5E | 2 | 20
LCSC | 0603WAF100JT5E.1 | UNI-ROYAL(厚声) | 0603WAF100JT5E |  | R0603 | R23,R24 | 0603WAF100JT5E | 2 | 21
LCSC | AS6C1008-55SIN.1 | Alliance Memory | AS6C1008-55SIN |  | SOP-32_L20.7-W11.3-P1.27-LS14.1-BL | U1,U2 | AS6C1008-55SIN | 2 | 22
LCSC | C547810 | Nexperia(安世) | 74HCT595PW,112 |  | TSSOP-16_L5.0-W4.4-P0.65-LS6.4-BL | U3,U4,U5,U6,U7,U8 | 74HCT595PW,112 | 6 | 23
LCSC | C53552921 | MDD(辰达半导体) | 74HCT541PW |  | TSSOP-20_L6.5-W4.4-P0.65-LS6.4-BL | U9,U10,U11,U12 | 74HCT541PW | 4 | 24
LCSC | C426701 | Nexperia(安世) | 74HCT245PW,118 |  | TSSOP-20_L6.5-W4.4-P0.65-LS6.4-BL | U13,U14 | 74HCT245PW,118 | 2 | 25
LCSC | C5986 | Nexperia(安世) | 74HCT32PW |  | TSSOP-14_L5.0-W4.4-P0.65-LS6.4-BL | U15 | 74HCT32PW | 1 | 26
LCSC | C547214 | Nexperia(安世) | 74HCT04PW,112 |  | TSSOP-14_L5.0-W4.4-P0.65-LS6.4-BL | U16 | 74HCT04PW,112 | 1 | 27
LCSC | C2872937 | TI(德州仪器) | SN74HCT08PW |  | TSSOP-14_L5.0-W4.4-P0.65-LS6.4-BL | U17 | SN74HCT08PW | 1 | 28
LCSC | C547417 | Nexperia(安世) | 74HCT173D,653 |  | SOP-16_L10.0-W3.9-P1.27-LS6.0-BL | U19 | 74HCT173D,653 | 1 | 29
LCSC | ES8388.1 | Everest-semi(顺芯) | ES8388 |  | QFN-28_L4.0-W4.0-P0.45-BL-EP | U20 | ES8388 | 1 | 30
LCSC | C3281959 | RENESAS(瑞萨)/IDT | SLG46826G |  | TSSOP-20_L6.5-W4.4-P0.65-LS6.4-BL | U21 | SLG46826G | 1 | 31

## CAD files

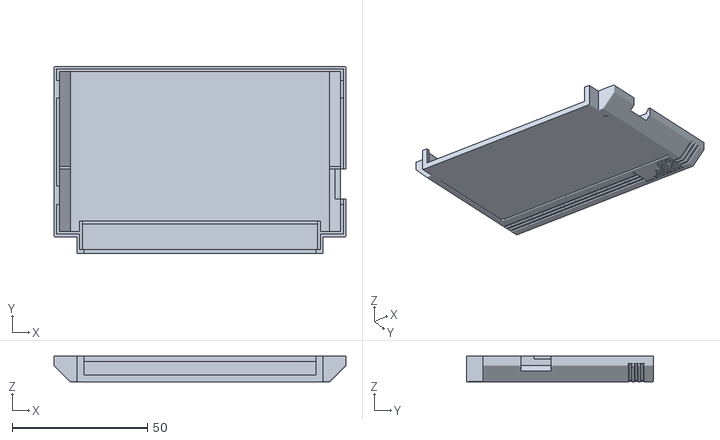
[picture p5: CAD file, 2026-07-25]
pcb/case/thing-3357677/files/Dendy_top_usb.stl
107.8 x 69.2 x 9.50

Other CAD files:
pcb/case/thing-3357677/files/Dendy.stl
pcb/case/thing-3357677/files/Dendy_top.stl

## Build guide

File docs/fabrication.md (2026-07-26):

# 製造仕様 (JLCPCB発注)

EasyEDA PCB2から生成した製造データは
[`pcb/fabrication/`](../pcb/fabrication/) にあります。ファイル構成は
[`pcb/README.md`](../pcb/README.md) を参照してください。

## 基板仕様

| 項目 | 指定 |
|---|---|
| 外形 | 純正段付き 90 × 56.8 mm(タン78.4mm/肩46.1mm/サイドノッチ深4.5mm@y20.9-22.9mm) |
| 層数 | 4層(L1=信号、L2=GNDベタ、L3=+5Vベタ、L4=信号) |
| **板厚** | **1.2 mm**(ファミコン仕様。1.6mm不可) |
| 表面処理 | **金フラッシュ(硬質金)+ 30°ベベル** 推奨(最低ENIG) |
| エッジフィンガー | 一辺のみ(下端)、60端子を同一幅1.600mm、先端テーパー、金メッキ、1mm以内に部品/ビア禁止 |
| 挿入側外形 | 左右下角 R1.524mm。ケースとの嵌合を現物確認 |
| 穴 | ネジ穴φ3@(39.5,19.8)/中央φ5@(45,10.3) NPTH |
| シルク | 両面(TOP=型番/値/コピーライト) |

## 実装

- 全IC/SRAM: TSSOP/TSOP、**片面(TOP)リフロー**
- M5Stamp S3: TOP面右上、USB右向き、手はんだ(キャステレーション/ヘッダ)
- ミラーリング: **JP1を垂直(V)に設定**(対象ゲームは垂直ミラー)

## 発注前チェックリスト

1. [ ] **エッジコネクタのピン1左右向き(鏡像)を実カートで確認** — 最重要。GND/+5V逆挿し防止
2. [ ] 自動配線(EasyEDA GUI)→ DRC クリーン(金フラッシュ1mmルール含む)
3. [ ] 3Dビューで M5Stamp とシェルの干渉確認
4. [ ] ガーバー生成後、発注画面で**完成板厚1.2mm・4層**を指定
5. [ ] 純正シェルに現物合わせ(外形・穴位置・タン厚)
6. [ ] 端子先端テーパー、左右下角R、30°ベベルの加工可否をPCBメーカーへ確認

## 構成部品(マッパー)

NROM(Mapper0)+ CNROM(Mapper3)両対応。CNROMバンクラッチ=U19(74HCT173)。
対象ゲーム `GOROman/calude-famicom-game`: CNROM/PRG32KB/CHR16KB/垂直ミラー。

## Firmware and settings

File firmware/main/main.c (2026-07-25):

// Famicom NROM cartridge — M5Stamp S3 ファームウェア
//
// 起動フロー:
//   1. GPIO を不活性状態で初期化 (バス衝突防止)
//   2. LittleFS マウント → autoload.txt のゲーム (無ければ game.nes) をSRAMへロード
//   3. LED緑 → ユーザーが本体RESETを押すとゲーム起動
//   4. softAP + Web UI でアップロード/ゲーム切替、拡張ポート経由パッド出力
//
// Bluetooth (BLE) コントローラ対応は Bluepad32 統合で joypad_out_set_buttons()
// に接続する予定 (docs/architecture.md 参照)。

#include <stdio.h>
#include <string.h>
#include "driver/gpio.h"
#include "esp_littlefs.h"
#include "esp_log.h"
#include "freertos/FreeRTOS.h"
#include "freertos/task.h"
#include "led_strip.h"

#include "cart_loader.h"
#include "audio.h"
#include "joypad_out.h"
#include "pins.h"
#include "web_server.h"

static const char *TAG = "main";
static led_strip_handle_t s_led;

static void set_led(uint8_t r, uint8_t g, uint8_t b)
{
    led_strip_set_pixel(s_led, 0, r, g, b);
    led_strip_refresh(s_led);
}

static void stat_led(bool on)
{
    gpio_set_level(PIN_LED_STAT, on ? 1 : 0);
}

void app_main(void)
{
    cart_loader_init();  // 最優先: バス不活性を確定

    // 基板上ステータスLED(赤)。ロード成否を内蔵SK6812と二重表示
    gpio_reset_pin(PIN_LED_STAT);
    gpio_set_direction(PIN_LED_STAT, GPIO_MODE_OUTPUT);
    stat_led(false);

    led_strip_config_t strip_cfg = {
        .strip_gpio_num = PIN_LED,
        .max_leds = 1,
    };
    led_strip_rmt_config_t rmt_cfg = { .resolution_hz = 10 * 1000 * 1000 };
    ESP_ERROR_CHECK(led_strip_new_rmt_device(&strip_cfg, &rmt_cfg, &s_led));
    set_led(32, 24, 0);  // 黄: ロード中

    esp_vfs_littlefs_conf_t fs_conf = {
        .base_path = "/littlefs",
        .partition_label = "storage",
        .format_if_mount_failed = true,
    };
    ESP_ERROR_CHECK(esp_vfs_littlefs_register(&fs_conf));

    // 前回選択ゲーム → 無ければ /game.nes
    char path[96] = "/littlefs/game.nes";
    FILE *f = fopen("/littlefs/autoload.txt", "r");
    if (f) {
        char name[64] = {0};
        if (fgets(name, sizeof(name), f)) {
            name[strcspn(name, "\r\n")] = 0;
            snprintf(path, sizeof(path), "/littlefs/%s", name);
        }
        fclose(f);
    }

    if (cart_load_game(path)) {
        set_led(0, 32, 0);  // 緑: RESET待ち
        stat_led(true);     // 基板LED点灯 = ロード完了、RESETを押す合図
    } else {
        ESP_LOGW(TAG, "no game loaded (%s)", path);
        set_led(32, 0, 0);  // 赤: 未ロード (Web UIからアップロード可)
        stat_led(false);
    }

    joypad_out_init();

    // ES8388はオプション実装。未実装・I2C応答なしでもカートリッジ機能は継続する。
    esp_err_t audio_err = audio_init();
    if (audio_err != ESP_OK) {
        ESP_LOGW(TAG, "audio disabled: %s", esp_err_to_name(audio_err));
    }

    web_server_start();

    vTaskDelete(NULL);
}

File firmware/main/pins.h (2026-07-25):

#pragma once

// M5Stamp S3 ピン割当
// --- SRAM ロード系 (74HCT595 チェーン) ---
#define PIN_SER_A    1   // PRG チェーン シリアルデータ
#define PIN_SER_B    2   // CHR チェーン シリアルデータ
#define PIN_SRCLK    3   // シフトクロック (両チェーン共有)
#define PIN_RCLK     4   // ラッチクロック (両チェーン共有)
#define PIN_OE_595   5   // 595 /OE (active-low, 共有)
#define PIN_WE_PRG   6   // PRG SRAM /WE
#define PIN_WE_CHR   7   // CHR SRAM /WE
#define PIN_MODE     8   // L=LOAD / H=RUN (基板プルダウン)

// --- 拡張ポート ジョイパッドエミュレーション (J2 → DA15 ケーブル) ---
#define PIN_JOY_OUT0 9   // DA15 pin12 OUT0 ストローブ (5V→分圧入力)
#define PIN_JOY_OE1  10  // DA15 pin14 /OE ($4016リード, 5V→分圧入力)
#define PIN_JOY_D1   11  // DA15 pin13 Joypad1 /D1 データ出力 (3.3V直=TTL H)

// --- ES8388 オーディオCODEC ---
#define PIN_I2S_MCLK 12  // ES8388 pin1 MCLK (48kHz時 12.288MHz)
#define PIN_I2S_BCLK 13  // ES8388 pin5 SCLK/BCLK
#define PIN_I2S_LRCK 15  // ES8388 pin7 LRCK
#define PIN_I2S_DOUT 39  // ES8388 pin6 DSDIN
#define PIN_I2C_SDA  40  // ES8388 pin27 CDATA
#define PIN_I2C_SCL  41  // ES8388 pin28 CCLK

// --- 基板上ディスクリートLED ---
#define PIN_LED_STAT 14  // 基板上ステータスLED(赤, GPIO High=点灯)。D2/R16経由
// 電源LED(緑, D1)は+5Vに直結で常時点灯、GPIO不要

// --- 内蔵 ---
#define PIN_LED      21  // SK6812 (M5Stamp内蔵、シェルで隠れる場合の代替が基板LED)
#define PIN_BTN      0   // BOOTボタン

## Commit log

2026-07-23 Famicom NROMカートリッジ設計初版: アーキテクチャ・ESP-IDFファームウェア
    - SRAMロード&ハンドオーバー方式 (M5Stamp S3 + AS6C62256 + 74HCT595/541/245)
    - WiFi softAPでの.nesアップロード/ゲーム切替 Web UI
    - 拡張ポート(DA15)経由ジョイパッドエミュレーション (BLEパッド対応の下地)
    - 純正シェル互換 90x46.1mm/1.2mm 60ピンエッジ仕様
    [partitions.csv]
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2026-07-24 hardware: EasyEDA Proで回路図・PCB設計を実施、実測ベースの外形/フィンガー仕様に更新
    - 回路図: 54部品・129ネット、ERCエラー0
    - PCB: 段付き外形100.33x40.64mm、エッジフィンガー60パッド、+5V/GNDベタ
    - フィンガー寸法を実績基板ガーバー実測値(1.8x7.62mm、ピン1ロング)に更新
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2026-07-24 hardware: 純正90x56.8mmプロファイル+穴位置、TSSOP/片面リフロー方針に更新
    - 外形を純正段付き90x56.8mmへ、板厚1.2mm(ファミコン仕様)
    - ネジ穴φ3@(39.5,19.8)/中央φ5@(45,10.3) 追加
    - 全ICをTSSOP/TSOP・片面実装に変更
2026-07-24 hardware: 片面TSSOPリフロー配置完了(純正90x56.8mm/穴/ベタ)、検証パス
    - 全IC TSSOP/TSOP化、片面(TOP)実装、パスコンIC隣接
    - M5Stamp USB右向き、53部品を穴/ノッチ/境界/重なりゼロで検証
    - 純正段付き外形+ネジ穴φ3/中央φ5配置
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2026-07-24 LED2個追加(電源緑/ステータス赤GPIO14)+ラッツネスト短縮のクラスタ再配置
    - 回路図: D1(緑,+5V常時)/D2(赤,GPIO14)/R15,R16(330Ω)追加、ERCエラー0
    - PCB: 接続クラスタ順配置(CHR左/PRG右、バッファをフィンガー寄り、パスコンIC隣接)、重なり0
    - FW: PIN_LED_STAT(GPIO14)でロード完了表示
2026-07-24 CNROM(Mapper3)対応: 74HCT173バンクラッチ追加、CHR16KB対応
    - 回路図: U19(74HCT173)追加、CHR SRAM A13/A14をバンク駆動化、595にA13/A14追加、74HCT32空きゲートで書込デコード
    - FW: CHR_SIZE 8KB→32KB(4バンク、16/8KBはミラー書込)
    - calude-famicom-game (CNROM/PRG32K/CHR16K/垂直ミラー) 対応
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2026-07-24 fix: サイドノッチを正規4.5mm深に修正(過大な11mmが基板領域認識を破綻させていた)
2026-07-24 pcb: EasyEDAプロジェクト(calude-rom-cartridge.eprj2)をpcb/で版管理開始
    保存ごとにこのファイルをコミットしていく運用の起点。
    現状: NROM+CNROM対応、58部品配置済み、外形/フィンガー/ベタ/シルク完了、配線前。
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2026-07-24 pcb: save 2026-07-24 18:05:22
2026-07-24 pcb: save 2026-07-24 18:05:31
2026-07-24 pcb: save 2026-07-24 18:06:10
2026-07-24 pcb: save 2026-07-24 18:06:50
2026-07-24 pcb: save 2026-07-24 18:06:59
2026-07-24 pcb: save 2026-07-24 18:07:08
2026-07-24 pcb: save 2026-07-24 18:07:17
2026-07-24 pcb: save 2026-07-24 18:07:26
2026-07-24 pcb: save 2026-07-24 18:07:36
2026-07-24 pcb: save 2026-07-24 18:07:45
2026-07-24 pcb: save 2026-07-24 18:07:54
2026-07-24 pcb: save 2026-07-24 18:08:03
2026-07-24 pcb: save 2026-07-24 18:08:23
2026-07-24 pcb: save 2026-07-24 18:08:32
2026-07-24 pcb: save 2026-07-24 18:08:41
2026-07-24 pcb: save 2026-07-24 18:09:20
2026-07-24 pcb: save 2026-07-24 18:09:30
2026-07-24 pcb: save 2026-07-24 18:12:51
2026-07-24 pcb: save 2026-07-24 18:13:26
2026-07-24 pcb: save 2026-07-24 18:14:12
2026-07-24 pcb: save 2026-07-24 18:16:08
2026-07-24 pcb: save 2026-07-24 18:16:18
2026-07-24 pcb: save 2026-07-24 18:21:42
2026-07-24 pcb: save 2026-07-24 18:22:01
2026-07-24 case: Dendy(thing:3357677)ケースSTLと適合解析を追加
    - STL解析: 外寸107.8x69.2mm、内部キャビティ96x62mm、底部スロット90mm
    - 現行基板90x56.8mm(タン78.4mm)が適合することを確認
    - pcb/case/にSTL2ファイルを版管理
    [Dendy.stl, Dendy_top.stl]
2026-07-24 case: Dendyケース(thing:3357677)一式をpcb/case/thing-3357677/へコピー
    README/LICENSE(CC-Attribution, 5rw)/images/STL を同梱。docs/case.mdのパス更新。
    [Dendy.stl, Dendy_top.stl]
2026-07-24 pcb: save 2026-07-24 18:30:02
2026-07-24 pcb: save 2026-07-24 18:34:06
2026-07-24 pcb: save 2026-07-24 18:35:47
2026-07-24 pcb: save 2026-07-24 18:36:52
2026-07-24 pcb: save 2026-07-24 18:37:48
2026-07-24 pcb: save 2026-07-24 18:38:38
2026-07-24 pcb: save 2026-07-24 18:53:08
2026-07-24 pcb: save 2026-07-24 18:58:48
2026-07-24 pcb: save 2026-07-24 19:04:15
2026-07-24 pcb: save 2026-07-24 19:31:25
2026-07-24 pcb: save 2026-07-24 19:31:55
2026-07-24 pcb: save 2026-07-24 19:40:31
2026-07-24 pcb: save 2026-07-24 19:41:00
2026-07-24 pcb: save 2026-07-24 19:41:30
2026-07-24 pcb: save 2026-07-24 19:41:49
2026-07-24 pcb: save 2026-07-24 19:41:58
2026-07-24 pcb: save 2026-07-24 19:43:29
2026-07-24 pcb: save 2026-07-24 19:43:38
2026-07-24 pcb: save 2026-07-24 19:43:47
2026-07-24 pcb: save 2026-07-24 19:44:01
2026-07-24 pcb: save 2026-07-24 19:44:09
2026-07-24 pcb: save 2026-07-24 19:44:18
2026-07-24 pcb: save 2026-07-24 19:44:28
2026-07-24 pcb: save 2026-07-24 19:44:37
2026-07-24 pcb: save 2026-07-24 19:44:46
2026-07-24 pcb: save 2026-07-24 19:44:55
2026-07-24 pcb: save 2026-07-24 19:45:03
2026-07-24 pcb: save 2026-07-24 19:45:12
2026-07-24 pcb: save 2026-07-24 19:45:42
2026-07-24 pcb: save 2026-07-24 19:47:19
2026-07-24 pcb: save 2026-07-24 19:47:28
2026-07-24 pcb: save 2026-07-24 19:47:38
2026-07-24 pcb: save 2026-07-24 19:47:53
2026-07-24 pcb: save 2026-07-24 19:48:02
2026-07-24 pcb: save 2026-07-24 19:48:12
2026-07-24 pcb: save 2026-07-24 19:48:21
2026-07-24 pcb: save 2026-07-24 19:48:36
2026-07-24 pcb: save 2026-07-24 19:48:45
2026-07-24 pcb: save 2026-07-24 19:48:54
2026-07-24 pcb: save 2026-07-24 19:49:04
2026-07-24 pcb: save 2026-07-24 19:49:13
2026-07-24 pcb: save 2026-07-24 19:49:22
2026-07-24 pcb: save 2026-07-24 19:49:32
2026-07-24 pcb: save 2026-07-24 19:49:41
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2026-07-24 docs: update fabrication spec for 4-layer 1.2mm PCB
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2026-07-25 Add audio, GreenPAK, and USB case updates
    [Dendy_top_usb.stl]
2026-07-26 Update PCB2 design and documentation
    Refresh PCB2 design assets, manufacturing outputs, documentation, and the README 3D preview.
    [calude-rom-cartridge-PCB2-bom.csv, calude-rom-cartridge-PCB2-pick-and-place.csv]
